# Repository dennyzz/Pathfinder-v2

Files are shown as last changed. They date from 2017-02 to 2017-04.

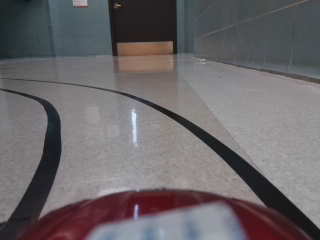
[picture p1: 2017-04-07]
images/track.png

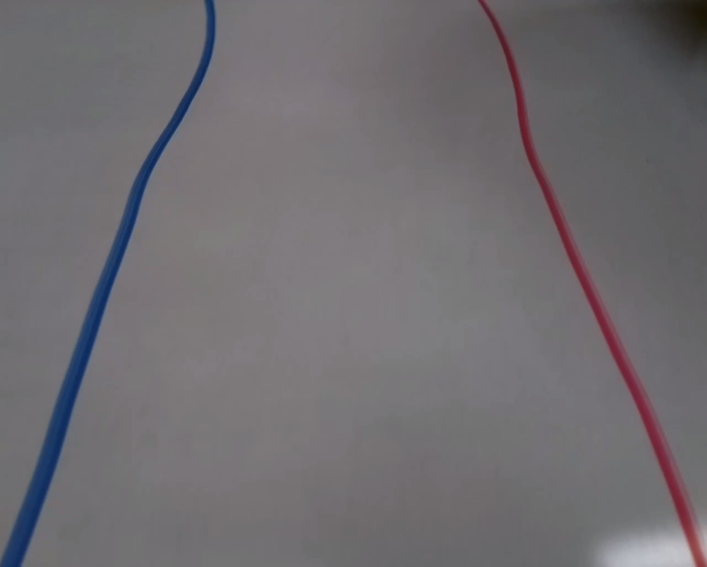
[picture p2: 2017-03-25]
images/lanestill.png

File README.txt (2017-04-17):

You are gonna need Python 3.x
The final working script for Pathfinder (RC Car) 
is 
# python3 curvepithreads.py

There are some Docs that explain setting up specific components on the Raspi in /Docs
/footage and /images are some resources we used for offline testing to verify the plausibilty of algorithms from a computer running python3
VL53L0X_rasp contains the library for the VL53L0X component 

The final files used for Pathfinder (RC Car) are
/curvepithreads.py << main program
/pathfindershield.py << import for commmuncations to chassis board
/PID.py 
support files
/VL53L0X_rasp liibrary needs to have # make run on it to compile the library for used
/logplot.py used for plotting the log file when logging is turned on
/lcd8+LED.py currently used as a startup script to display the ip address and blink the headlights on boot
Extra files
Previous iterations
/curve.py and /threadex.py are meant to run on a regular computer for testing
/curvepi.py is the non-threaded version of the pathfinder program
/VL53L0X_ex.py is the test file for that component

Other project resources
lots of other files of code written...
PCB is located in /Chassis Controller/PCB made in Altium, though Gerber files are zipped
Firmware for the ATMega328P on the Chassis is in /Chassis Controller/Pathfinderinterface made in Atmel Studio

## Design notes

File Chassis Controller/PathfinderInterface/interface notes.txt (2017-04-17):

Pathfinder Board interface 
input TWI 
8-bit PWM

on revision 1 we cannot implement the full stackup of commands since we have bugs in the HW

Since Timer1 is the high resolution we use it for the servos, and connect 

// not valid on HW1
TWI command Chart
Pathfinder Interface Address : 0x5A = 'Z'

Commands: 
Motor_CMD_TYPE_1
// not valid on HW1 
| ADDR | CMD1 | MotorA_CTRL | MotorA_SPD | MotorB_CTRL | MotorB_SPD | Servo1  | Servo2  |
| 0x5A | 0x01 | uint8_t     | uint8_t    | uint8_t     | uint8_t    | uint8_t | uint8_t |

Motor_CMD_TYPE_2 
// not valid on HW1 
| ADDR | CMD2 | MotorA_CTRL | MotorA_SPD | MotorB_CTRL | MotorB_SPD |
| 0x5A | 0x02 | uint8_t     | uint8_t    | uint8_t     | uint8_t    |

Motor_CMD_TYPE_3 
| ADDR | CMD3 | MotorA_CTRL | MotorA_SPD | Servo1  | 
| 0x5A | 0x03 | uint8_t     | uint8_t    | uint8_t | 

Motor_CMD_TYPE_4 
| ADDR | CMD4 | MotorB_CTRL | MotorB_SPD | Servo2  | 
| 0x5A | 0x04 | uint8_t     | uint8_t    | uint8_t | 

LED_CMD
| ADDR | CMD4 | LED_BITS | 
| 0x5A | 0x10 | uint8_t  |

Each MotorX_CTRL byte contains 
DIR_BIT 0
BRAKE_BIT 1

each MotorX_SPD byte is 
0-255 value for PWM motor speed

each ServoN byte is
0-255 value from full left to full right with 127 being approximately centered

LED_BITS
bit channels are from 
| LED | 7   | 6   | 5   | 4   | 3   | 2   | 1   | 0   |
| LED | PD4 | PD2 | PD1 | PD0 | PC3 | PC2 | PC1 | PC0 |

pinmap!

PC0
PC1
PC2
PC3
PC4	SDA
PC5	SCL
PC6	RST

PD0
PD1
PD2
PD3 SERVO2	OC2B
PD4
PD5	BPWM2	OC0B
PD6	BPWM1	OC0A
PD7	BnSLEEP

PB0	AnSLEEP
PB1	APWM1	OC1A
PB2	APWM2	OC1B
PB3 MOSI SERVO1 OC2A
PB4	MISO
PB5	SCK

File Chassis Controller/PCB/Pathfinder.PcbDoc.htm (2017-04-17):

Reporting Options

# File in Previous Format

Date | : | 4/17/2017
Time | : | 11:50:48 AM
Filename | : | C:\Users\Denny\Dropbox\Homework\452\Project\PCB\Pathfinder.PcbDoc

Version | Warning

This file was generated by an earlier version of the software

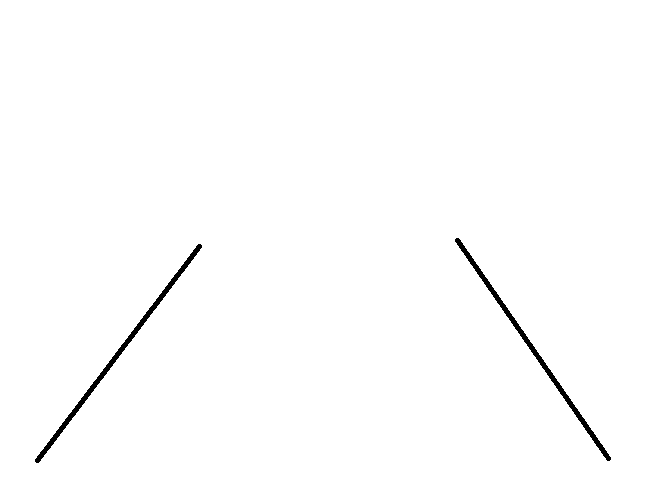
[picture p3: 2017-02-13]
images/lines.jpg

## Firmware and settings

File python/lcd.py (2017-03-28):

#!/usr/bin/python2.7

from subprocess import *
from time import sleep, strftime
from datetime import datetime

import time

import Adafruit_GPIO as GPIO
import Adafruit_GPIO.I2C as I2C
import Adafruit_GPIO.MCP230xx as MCP
import Adafruit_GPIO.PWM as PWM


# Commands
LCD_CLEARDISPLAY        = 0x01
LCD_RETURNHOME          = 0x02
LCD_ENTRYMODESET        = 0x04
LCD_DISPLAYCONTROL      = 0x08
LCD_CURSORSHIFT         = 0x10
LCD_FUNCTIONSET         = 0x20
LCD_SETCGRAMADDR        = 0x40
LCD_SETDDRAMADDR        = 0x80

# Entry flags
LCD_ENTRYRIGHT          = 0x00
LCD_ENTRYLEFT           = 0x02
LCD_ENTRYSHIFTINCREMENT = 0x01
LCD_ENTRYSHIFTDECREMENT = 0x00

# Control flags
LCD_DISPLAYON           = 0x04
LCD_DISPLAYOFF          = 0x00
LCD_CURSORON            = 0x02
LCD_CURSOROFF           = 0x00
LCD_BLINKON             = 0x01
LCD_BLINKOFF            = 0x00

# Move flags
LCD_DISPLAYMOVE         = 0x08
LCD_CURSORMOVE          = 0x00
LCD_MOVERIGHT           = 0x04
LCD_MOVELEFT            = 0x00

# Function set flags
LCD_8BITMODE            = 0x10
LCD_4BITMODE            = 0x00
LCD_2LINE               = 0x08
LCD_1LINE               = 0x00
LCD_5x10DOTS            = 0x04
LCD_5x8DOTS             = 0x00

# Offset for up to 4 rows.
LCD_ROW_OFFSETS         = (0x00, 0x40, 0x14, 0x54)

# Char LCD plate GPIO numbers.
LCD_PLATE_RS            = 15
LCD_PLATE_RW            = 14
LCD_PLATE_EN            = 13
LCD_PLATE_D4            = 12
LCD_PLATE_D5            = 11
LCD_PLATE_D6            = 10
LCD_PLATE_D7            = 9
LCD_PLATE_RED           = 6
LCD_PLATE_GREEN         = 7
LCD_PLATE_BLUE          = 8

# Char LCD plate button names.
SELECT                  = 0
RIGHT                   = 1
DOWN                    = 2
UP                      = 3
LEFT                    = 4

class Adafruit_CharLCD(object):
    """Class to represent and interact with an HD44780 character LCD display."""

    def __init__(self, rs, rw, en, d4, d5, d6, d7, cols, lines, backlight=None,
                    invert_polarity=True,
                    enable_pwm=False,
                    gpio=GPIO.get_platform_gpio(),
                    pwm=PWM.get_platform_pwm(),
                    initial_backlight=1.0):
        """Initialize the LCD.  RS, EN, and D4...D7 parameters should be the pins
        connected to the LCD RS, clock enable, and data line 4 through 7 connections.
        The LCD will be used in its 4-bit mode so these 6 lines are the only ones
        required to use the LCD.  You must also pass in the number of columns and
        lines on the LCD.  
        If you would like to control the backlight, pass in the pin connected to
        the backlight with the backlight parameter.  The invert_polarity boolean
        controls if the backlight is one with a LOW signal or HIGH signal.  The 
        default invert_polarity value is True, i.e. the backlight is on with a
        LOW signal.  
        You can enable PWM of the backlight pin to have finer control on the 
        brightness.  To enable PWM make sure your hardware supports PWM on the 
        provided backlight pin and set enable_pwm to True (the default is False).
        The appropriate PWM library will be used depending on the platform, but
        you can provide an explicit one with the pwm parameter.
        The initial state of the backlight is ON, but you can set it to an 
        explicit initial state with the initial_backlight parameter (0 is off,
        1 is on/full bright).
        You can optionally pass in an explicit GPIO class,
        for example if you want to use an MCP230xx GPIO extender.  If you don't
        pass in an GPIO instance, the default GPIO for the running platform will
        be used.
        """
        # Save column and line state.
        self._cols = cols
        self._lines = lines
        # Save GPIO state and pin numbers.
        self._gpio = gpio
        self._rs = rs
        self._rw = rw
        self._en = en
        self._d4 = d4
        self._d5 = d5
        self._d6 = d6
        self._d7 = d7
        # Save backlight state.
        self._backlight = backlight
        self._pwm_enabled = enable_pwm
        self._pwm = pwm
        self._blpol = not invert_polarity
        # Setup all pins as outputs.
        for pin in (rs, rw, en, d4, d5, d6, d7):
            gpio.setup(pin, GPIO.OUT)
        # Setup backlight.
        if backlight is not None:
            if enable_pwm:
                pwm.start(backlight, self._pwm_duty_cycle(initial_backlight))
            else:
                gpio.setup(backlight, GPIO.OUT)
                gpio.output(backlight, self._blpol if initial_backlight else not self._blpol)
        # Initialize the display.
        self._gpio.output(self._en, False)
        self.write8(0x02)
        self.write8(0x28)
        # Initialize display control, function, and mode registers.
        self.displaycontrol = LCD_DISPLAYON | LCD_CURSOROFF | LCD_BLINKOFF
        self.displayfunction = LCD_4BITMODE | LCD_1LINE | LCD_2LINE | LCD_5x8DOTS
        self.displaymode = LCD_ENTRYLEFT | LCD_ENTRYSHIFTDECREMENT
        # Write registers.
        self.write8(LCD_DISPLAYCONTROL | self.displaycontrol)
        self.write8(LCD_FUNCTIONSET | self.displayfunction)
        self.write8(LCD_ENTRYMODESET | self.displaymode)  # set the entry mode
        self.clear()

    def home(self):
        """Move the cursor back to its home (first line and first column)."""
        self.write8(LCD_RETURNHOME)  # set cursor position to zero
        self._delay_microseconds(3000)  # this command takes a long time!

    def clear(self):
        """Clear the LCD."""
        self.write8(LCD_CLEARDISPLAY)  # command to clear display
        self._delay_microseconds(3000)  # 3000 microsecond sleep, clearing the display takes a long time

    def set_cursor(self, col, row):
        """Move the cursor to an explicit column and row position."""
        # Clamp row to the last row of the display.
        if row > self._lines:
            row = self._lines - 1
        # Set location.
        self.write8(LCD_SETDDRAMADDR | (col + LCD_ROW_OFFSETS[row]))

    def enable_display(self, enable):
        """Enable or disable the display.  Set enable to True to enable."""
        if enable:
            self.displaycontrol |= LCD_DISPLAYON
        else:
            self.displaycontrol &= ~LCD_DISPLAYON
        self.write8(LCD_DISPLAYCONTROL | self.displaycontrol)

    def show_cursor(self, show):
        """Show or hide the cursor.  Cursor is shown if show is True."""
        if show:
            self.displaycontrol |= LCD_CURSORON
        else:
            self.displaycontrol &= ~LCD_CURSORON
        self.write8(LCD_DISPLAYCONTROL | self.displaycontrol)

    def blink(self, blink):
        """Turn on or off cursor blinking.  Set blink to True to enable blinking."""
        if blink:
            self.displaycontrol |= LCD_BLINKON
        else:
            self.displaycontrol &= ~LCD_BLINKON
        self.write8(LCD_DISPLAYCONTROL | self.displaycontrol)

    def move_left(self):
        """Move display left one position."""
        self.write8(LCD_CURSORSHIFT | LCD_DISPLAYMOVE | LCD_MOVELEFT)

    def move_right(self):
        """Move display right one position."""
        self.write8(LCD_CURSORSHIFT | LCD_DISPLAYMOVE | LCD_MOVERIGHT)

    def set_left_to_right(self):
        """Set text direction left to right."""
        self.displaymode |= LCD_ENTRYLEFT
        self.write8(LCD_ENTRYMODESET | self.displaymode)

    def set_right_to_left(self):
        """Set text direction right to left."""
        self.displaymode &= ~LCD_ENTRYLEFT
        self.write8(LCD_ENTRYMODESET | self.displaymode)

    def autoscroll(self, autoscroll):
        """Autoscroll will 'right justify' text from the cursor if set True,
        otherwise it will 'left justify' the text.
        """
        if autoscroll:
            self.displaymode |= LCD_ENTRYSHIFTINCREMENT
        else:
            self.displaymode &= ~LCD_ENTRYSHIFTINCREMENT
        self.write8(LCD_ENTRYMODESET | self.displaymode)

    def message(self, text):
        """Write text to display.  Note that text can include newlines."""
        line = 0
        # Iterate through each character.
        for char in text:
            # Advance to next line if character is a new line.
            if char == '\n':
                line += 1
                # Move to left or right side depending on text direction.
                col = 0 if self.displaymode & LCD_ENTRYLEFT > 0 else self._cols-1
                self.set_cursor(col, line)
            # Write the character to the display.
            else:
                self.write8(ord(char), True)

    def set_backlight(self, backlight):
        """Enable or disable the backlight.  If PWM is not enabled (default), a
        non-zero backlight value will turn on the backlight and a zero value will
        turn it off.  If PWM is enabled, backlight can be any value from 0.0 to
        1.0, with 1.0 being full intensity backlight.
        """
        if self._backlight is not None:
            if self._pwm_enabled:
                self._pwm.set_duty_cycle(self._backlight, self._pwm_duty_cycle(backlight))
            else:
                self._gpio.output(self._backlight, self._blpol if backlight else not self._blpol)

    def write8(self, value, char_mode=False):
        """Write 8-bit value in character or data mode.  Value should be an int
        value from 0-255, and char_mode is True if character data or False if
        non-character data (default).
        """
        # One millisecond delay to prevent writing too quickly.
        self._delay_microseconds(1000)
        # Set character / data bit.
        self._gpio.output(self._rs, char_mode)
        # Write upper 4 bits.
        self._gpio.output_pins({ self._d4: ((value >> 4) & 1) > 0,
                                 self._d5: ((value >> 5) & 1) > 0,
                                 self._d6: ((value >> 6) & 1) > 0,
                                 self._d7: ((value >> 7) & 1) > 0 })
        self._pulse_enable()
        # Write lower 4 bits.
        self._gpio.output_pins({ self._d4: (value        & 1) > 0,
                                 self._d5: ((value >> 1) & 1) > 0,
                                 self._d6: ((value >> 2) & 1) > 0,
                                 self._d7: ((value >> 3) & 1) > 0 })
        self._pulse_enable()

    def create_char(self, location, pattern):
        """Fill one of the first 8 CGRAM locations with custom characters.
        The location parameter should be between 0 and 7 and pattern should
        provide an array of 8 bytes containing the pattern. E.g. you can easyly
        design your custom character at http://www.quinapalus.com/hd44780udg.html
        To show your custom character use eg. lcd.message('\x01')
        """
        # only position 0..7 are allowed
        location &= 0x7
        self.write8(LCD_SETCGRAMADDR | (location << 3))
        for i in range(8):
            self.write8(pattern[i], char_mode=True)

    def _delay_microseconds(self, microseconds):
        # Busy wait in loop because delays are generally very short (few microseconds).
        end = time.time() + (microseconds/1000000.0)
        while time.time() < end:
            pass

    def _pulse_enable(self):
        # Pulse the clock enable line off, on, off to send command.
        self._gpio.output(self._en, False)
        self._delay_microseconds(1)       # 1 microsecond pause - enable pulse must be > 450ns
        self._gpio.output(self._en, True)
        self._delay_microseconds(1)       # 1 microsecond pause - enable pulse must be > 450ns
        self._gpio.output(self._en, False)
        self._delay_microseconds(1)       # commands need > 37us to settle

    def _pwm_duty_cycle(self, intensity):
        # Convert intensity value of 0.0 to 1.0 to a duty cycle of 0.0 to 100.0
        intensity = 100.0*intensity
        # Invert polarity if required.
        if not self._blpol:
            intensity = 100.0-intensity
        return intensity








lcd = Adafruit_CharLCD(2,14,3,4,17,27,22,16,2)
lcd.clear()

cmd = "ip addr show wlan0 | grep -m 1 inet | awk '{print $2}' | cut -d/ -f1"


def run_cmd(cmd):
        p = Popen(cmd, shell=True, stdout=PIPE)
        output = p.communicate()[0]
        return output

while 1:
        lcd.home()
        ipaddr = run_cmd(cmd)
        #print datetime.now().strftime('%b %d  %H:%M:%S\
        lcd.message(datetime.now().strftime('%b %d  %H:%M:%S\n'))
        lcd.message('IP%15s' % ( ipaddr ) )
        sleep(1)

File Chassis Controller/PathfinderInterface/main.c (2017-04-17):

#include "pathfinder.h"

int main(void){
	init();
	// default "register" values
	rxbuffer[0] = 0;
	rxbuffer[1] = 0;
	rxbuffer[2] = 0;
	rxbuffer[3] = 0;
	rxbuffer[4] = 0;
	rxbuffer[5] = 128;
	rxbuffer[6] = 128;
	rxbuffer[7] = 0;

	I2C_init(0x5A); // initalize as slave with address 0x5A
	
	// allow interrupts
	sei();
	set_sleep_mode(SLEEP_MODE_IDLE);
	
	while(1){
		sleep_enable();
		sei();
		sleep_cpu();
		sleep_disable();
		// on every interrupt, awke and update from the registers
		update();
		// convert receiver buffer index 0 to character array and send it via UART
	}
	
	return 0;
}

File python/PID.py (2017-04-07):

#The recipe gives simple implementation of a Discrete Proportional-Integral-Derivative (PID) controller. PID controller gives output value for error between desired reference input and measurement feedback to minimize error value.
#More information: http://en.wikipedia.org/wiki/PID_controller
#
#cnr437@gmail.com
#
#######	Example	#########
#
#p=PID(3.0,0.4,1.2)
#p.setPoint(5.0)
#while True:
#     pid = p.update(measurement_value)
#
#


class PID:
	"""
	Discrete PID control
	"""

	def __init__(self, P=2.0, I=0.0, D=1.0, Derivator=0, Integrator=0, Integrator_max=500, Integrator_min=-500):

		self.Kp=P
		self.Ki=I
		self.Kd=D
		self.Derivator=Derivator
		self.Integrator=Integrator
		self.Integrator_max=Integrator_max
		self.Integrator_min=Integrator_min

		self.set_point=0.0
		self.error=0.0

	def update(self,current_value):
		"""
		Calculate PID output value for given reference input and feedback
		"""

		self.error = self.set_point - current_value

		self.P_value = self.Kp * self.error
		self.D_value = self.Kd * ( self.error - self.Derivator)
		self.Derivator = self.error

		self.Integrator = self.Integrator + self.error

		if self.Integrator > self.Integrator_max:
			self.Integrator = self.Integrator_max
		elif self.Integrator < self.Integrator_min:
			self.Integrator = self.Integrator_min

		self.I_value = self.Integrator * self.Ki

		PID = self.P_value + self.I_value + self.D_value

		return PID

	def update_error(self, error):
		self.P_value = self.Kp * error
		self.D_value = self.Kd * ( error - self.Derivator)
		self.Derivator = error

		self.Integrator = self.Integrator + error

		if self.Integrator > self.Integrator_max:
			self.Integrator = self.Integrator_max
		elif self.Integrator < self.Integrator_min:
			self.Integrator = self.Integrator_min

		self.I_value = self.Integrator * self.Ki

		PID = self.P_value + self.I_value + self.D_value

		return PID

	def setPoint(self,set_point):
		"""
		Initilize the setpoint of PID
		"""
		self.set_point = set_point
		self.Integrator=0
		self.Derivator=0

	def setIntegrator(self, Integrator):
		self.Integrator = Integrator

	def setDerivator(self, Derivator):
		self.Derivator = Derivator

	def setKp(self,P):
		self.Kp=P

	def setKi(self,I):
		self.Ki=I

	def setKd(self,D):
		self.Kd=D

	def getPoint(self):
		return self.set_point

	def getError(self):
		return self.error

	def getIntegrator(self):
		return self.Integrator

	def getDerivator(self):
		return self.Derivator

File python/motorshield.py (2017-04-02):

#!/usr/bin/python

#define PCA9685_MODE1 0x0
#define PCA9685_PRESCALE 0xFE

import smbus
import sys


# Usage: 
# Select is motor 1 or 2 , none other are implemented
# Speed is a value from 0 to 4096 corresponding to 0 to full scale pwm
# dir is the direction of rotation, the motors will need to be opposites to move forwards
# brake is if 1 then brake, and ignore all else

def motorcmd(select, speed, dir, brake):
    # motor select 1 and 2 are M1 M2 channels
    bus = smbus.SMBus(1)    # 0 = /dev/i2c-0 (port I2C0), 1 = /dev/i2c-1 (port I2C1)
    DEVICE_ADDRESS = 0x60      #7 bit address (will be left shifted to add the read write bit)
    DEVICE_REG_LED_BASE = 0x06
    DEVICE_REG_MOT1PWM = 0x06+8*4
    DEVICE_REG_MOT1A = 0x06+10*4
    DEVICE_REG_MOT1B = 0x06+9*4
    DEVICE_REG_MOT2PWM = 0x06+13*4
    DEVICE_REG_MOT2A = 0x06+11*4
    DEVICE_REG_MOT2B = 0x06+12*4

    PCA9685_MODE1 = 0x0
    PCA9685_PRESCALE = 0xFE
    PCA_MODE = 0x21
    bus.write_byte_data(DEVICE_ADDRESS, PCA9685_MODE1, PCA_MODE | 0x10)
    bus.write_byte_data(DEVICE_ADDRESS, PCA9685_PRESCALE, 0x64) #54Hz ish
    bus.write_byte_data(DEVICE_ADDRESS, PCA9685_PRESCALE, 0x0) #54Hz ish
    bus.write_byte_data(DEVICE_ADDRESS, PCA9685_MODE1, PCA_MODE)
    pwm_on = [0x00, 0x10, 0xFF, 0x0F]
    pwm_off = [0x00, 0x00, 0xFF, 0x1F]
    bitspeed = speed & 0xFFF
    pwm_speed = [bitspeed & 0xFF, (bitspeed >> 8)&0x0F, 0xFF, 0x0F]
    #Write a single register
    # bus.write_byte_data(DEVICE_ADDRESS, DEVICE_REG_MODE1, 0x80)

    #Write an array of
    if (select == 1):
        motA = DEVICE_REG_MOT1A
        motB = DEVICE_REG_MOT1B
        motPWM = DEVICE_REG_MOT1PWM
    elif(select == 2):
        motA = DEVICE_REG_MOT2A
        motB = DEVICE_REG_MOT2B
        motPWM = DEVICE_REG_MOT2PWM
    else:
        print("wtf")

    bus.write_i2c_block_data(DEVICE_ADDRESS, motPWM, pwm_on)
    if(brake):
        bus.write_i2c_block_data(DEVICE_ADDRESS, motA, pwm_on)
        bus.write_i2c_block_data(DEVICE_ADDRESS, motB, pwm_on)
    elif(speed == 4096):
        bus.write_i2c_block_data(DEVICE_ADDRESS, motA, pwm_off)
        bus.write_i2c_block_data(DEVICE_ADDRESS, motB, pwm_off)
    else:
        if(dir == 1):
            bus.write_i2c_block_data(DEVICE_ADDRESS, motA, pwm_speed)
            bus.write_i2c_block_data(DEVICE_ADDRESS, motB, pwm_off)
        else:
            bus.write_i2c_block_data(DEVICE_ADDRESS, motA, pwm_off)
            bus.write_i2c_block_data(DEVICE_ADDRESS, motB, pwm_speed)
    

    

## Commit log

2017-03-06 PWM file for testing on the pi
2017-03-21 motor test python
2017-03-21 motor test tab...
2017-03-21 trying things with the arduino motor shield
2017-03-22 something working for motor control
2017-03-22 working motor test thing
2017-03-22 motor test working, also add cameraunified to vl folder
2017-03-25 add the lcd driver code and HDMI command reference
2017-03-27 add some comments for motor control
2017-03-28 lcd update with correct pins
    [lcd8.py]
2017-03-29 fix some lcd8 things finally workng
    [lcd8.py]
2017-03-30 tentative final executable
    has checks for slopes of lines and changes motor pwm's depending on
    slopes of lines; checks distance too and stops vehicle if sensor tripped
2017-04-02 update motortest -> motorshield
2017-04-02 write a servo test command for the car
2017-04-03 fixing up the pathfinder shield and add a fun servo test
    [pathfindershield.py, servotest2.py]
2017-04-03 updated file to talk to motors on jank robot
    only getting motors to talk, can't talk with distance sensor
2017-04-03 small updates to bezier pi and servo testing
2017-04-05 add the distance sensor into the mix
2017-04-06 minor changes test of sensor for pathfindercar
2017-04-07 small updates, and add the track image for static testing
2017-04-07 trying a pid loop with code from online ! needs tuning and sign checking
2017-04-07 modify pathfinder boot script to add LED blink
2017-04-11 working threadex and start port to pi
2017-04-11 fix the scanheight change
    [curvepi.py]
2017-04-11 update the threads to include full output
2017-04-11 first log file, try to plot things with it
    [log.csv]
2017-04-11 more log files
    [logd05.csv, logd10.csv, logd5.csv]
2017-04-11 more logs
    [logp2d1.csv]
2017-04-11 decent run log transfer
    [logp05d1.csv]
2017-04-11 add the logplot file
    [logp1d1.csv]
2017-04-11 running faster
    [log.csv]
2017-04-11 add the angle measurement config value
    [logs65p04d1.csv]
2017-04-12 reset distance stop to 250
    [curvepithreads.py]
2017-04-12 curvepi trying to draw angle and offset error lines
    [curve.py, curvepithreads.py]
2017-04-12 merging pathfinder's curvepi
    [log.csv, logd05.csv, logd10.csv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]
2017-04-17 Add Atmel Studio project for the Chassis controller board
2017-04-17 Add Altium PCB files for the Chassis Controller
    [Pathfinder.PcbDoc, Pathfinder.PrjPcb, Pathfinder.SchDoc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]
2017-04-18 small commits of code for the presentation
    [log.csv]
2017-04-20 add a python to test some other camera settings
2017-05-22 move pythons and add blank cpps
    [log.csv]
